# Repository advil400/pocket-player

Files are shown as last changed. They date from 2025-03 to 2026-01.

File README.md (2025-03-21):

# pocket-player

open hardware portable music player and personal computer\
customizable public good for everyday listening and other habits\
\
towards new ways of living & new ecologies of minds and matter

eng. Waking+Life\
prod. 99.9%Pure\
[CERN-OHL-S-2.0](https://choosealicense.com/licenses/cern-ohl-s-2.0/)

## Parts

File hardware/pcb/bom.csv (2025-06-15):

Designator | Quantity | Value | Footprint | Package | MPN | DNP | Mount_Type | Description | Manufacturer_Name | Height | Mouser Part Number | Mouser Price/Stock
C1, C43, C44, C46, C47, C52, C8 | 7 | 10uF | C_0805_2012Metric |  | GRM21BZ71E106KE15K |  | smt | Unpolarized capacitor, small symbol | Murata
C10, C13, C16, C19, C2, C21, C23, C3, C33, C34, C35, C36, C37, C38, C39, C4, C40, C41, C5, C6, C7, C9 | 22 | 100nF | C_0402_1005Metric |  | GRM155R71H104KE14D |  | smt | Unpolarized capacitor, small symbol | Murata
C11, C12 | 2 | 10pF | C_0402_1005Metric |  | GRM1555C1E100GA01D |  | smt | Unpolarized capacitor, small symbol | Murata
C14, C15, C17, C18, C25, C26, C27, C28, C29, C30, C31, C32, C49, C50 | 14 | 2u2 | C_0805_2012Metric |  | GRM21BR71E225KE11L |  | smt | Unpolarized capacitor, small symbol | Murata
C20, C48, C51 | 3 | 4u7 | C_0805_2012Metric |  | GRM21BZ71H475KE15L |  | smt | Unpolarized capacitor, small symbol | Murata
C22, C24 | 2 | 15uF | C_1206_3216Metric |  | GRT31CR60J156KE01L |  | smt | Unpolarized capacitor, small symbol | Murata
C42 | 1 | 1uF | C_0805_2012Metric |  | GCM21BR71H105KA03L |  | smt | Unpolarized capacitor, small symbol | Murata
C45 | 1 | 47nF | C_0603_1608Metric |  | GCM188R71H473KA55D |  | smt | Unpolarized capacitor, small symbol | Murata
D1 | 1 | STAT_LED | LED_Wurth_150044M155260 |  | 150044M155260 |  | smt | RGB LED, red/green/blue/anode | Wurth Elektronik
D2, D3, D4, D5, D6, D7 | 6 | PESD3V3L1BA | D_SOD-323F |  | PESD3V3L1BA,115 |  | smt | Bidirectional transient-voltage-suppression diode, small symbol | Nexperia
D8 | 1 | ~ | LED_0402_1005Metric |  | 150040VS73240 |  | smt | Light emitting diode | Wurth Elektronik
FB1, FB2 | 2 | 120R | R_0805_2012Metric |  | BLM21AG121BH1D |  | smt | Ferrite bead, small symbol | Murata
J2 | 1 | microSD PushPush Receptacle | microSD_HC_Hirose_DM3AT-SF-PEJM5 |  | DM3AT-SF-PEJM5 |  | smt | Micro SD Card Socket with one card detection pin | Hirose
J3 | 1 | AudioJack3_SwitchT | SAMESKY_SJ3-35083B-TR |  | SJ3-35083B-TR |  | tht | Audio Jack, 3 Poles (Stereo / TRS), Switched T Pole (Normalling)
J4 | 1 | USB_C_Input | USB_C_Receptacle_GCT_USB4105-xx-A_16P_TopMnt_Horizontal |  | USB4105-GF-A |  | smt | USB 2.0-only 14P Type-C Receptacle connector | GCT
J5 | 1 | Molex 3p 1.25mm | Molex_PicoBlade_53048-0310_1x03_P1.25mm_Horizontal |  | 53048-0310 |  | tht | Molex PicoBlade 3-pin 1.25mm pitch | Molex
L1 | 1 | 2u2 | L_Coilcraft_XAL4020-XXX |  | XAL4020-222MEC |  | smt | Inductor, small symbol | Coilcraft
L2 | 1 | 2u2 | L_Murata_DFE201610P |  | DFE201612E-2R2M=P2 |  | smt | Inductor, small symbol | Murata
R1, R15, R17, R18, R19, R2, R20, R3, R48, R5, R6, R7, R8, R9 | 14 | 33R | R_0603_1608Metric |  | RT0603DRD0747RL |  | smt | Resistor, small symbol | Yageo
R10, R11, R12, R13, R14, R16, R24, R25, R26, R30, R31, R34, R38, R39, R4, R40, R41, R42, R46 | 19 | 10k | R_0603_1608Metric |  | AT0603FRD0710KL |  | smt | Resistor, small symbol | Yageo
R21, R22, R23 | 3 | 2k2 | R_0603_1608Metric |  | AT0603FRE072K2L |  | smt | Resistor, small symbol | Yageo
R27, R28, R29, R32, R33, R35 | 6 | 1k | R_0603_1608Metric |  | RT0603FRD071KL |  | smt | Resistor, small symbol | Yageo
R36, R37, R43 | 3 | 5k1 | R_0603_1608Metric |  | RT0603FRD075K1L |  | smt | Resistor, small symbol | Yageo
R44 | 1 | 360R | R_0603_1608Metric |  | RT0603FRE07360RL |  | smt | Resistor, small symbol | Yageo
R45 | 1 | 31k6 | R_0603_1608Metric |  | RT0603BRD0731K6L |  | smt | Resistor, small symbol | Yageo
R47 | 1 | 52.3k | R_0603_1608Metric |  | RT0603BRD0752K3L |  | smt | Resistor, small symbol | Yageo
SW1 | 1 | PREV | Panasonic_EVQPUJ_EVQPUA |  | EVQ-PUA02K |  | smt | Push button switch, generic, two pins | Panasonic
SW2 | 1 | VOL+ | Panasonic_EVQPUJ_EVQPUA |  | EVQ-PUA02K |  | smt | Push button switch, generic, two pins | Panasonic
SW3 | 1 | PWR_BTN | Panasonic_EVQPUJ_EVQPUA |  | EVQ-PUA02K |  | smt | Push button switch, generic, two pins | Panasonic
SW4 | 1 | NEXT | Panasonic_EVQPUJ_EVQPUA |  | EVQ-PUA02K |  | smt | Push button switch, generic, two pins | Panasonic
SW5 | 1 | VOL- | Panasonic_EVQPUJ_EVQPUA |  | EVQ-PUA02K |  | smt | Push button switch, generic, two pins | Panasonic
SW6 | 1 | PLAY | Panasonic_EVQPUJ_EVQPUA |  | EVQ-PUA02K |  | smt | Push button switch, generic, two pins | Panasonic
U1 | 1 | STM32F405RGTx | LQFP-64_10x10mm_P0.5mm |  | STM32F405RGT6 |  | smt | STMicroelectronics Arm Cortex-M4 MCU, 1024KB flash, 192KB RAM, 168 MHz, 1.8-3.6V, 51 GPIO, LQFP64 | STMicroelectronics
U2 | 1 | CS43131CNZ | CS43131-CNZR_QFN40 |  | CS43131-CNZR |  | smt |  | Cirrus Logic
U3 | 1 | BQ241920-RGER | Texas_RGE0024H_VQFN-24-1EP_4x4mm_P0.5mm_EP2.7x2.7mm |  | BQ24190RGER |  | smt |  | Texas Instruments
U4 | 1 | USBLC6-2P6 | SOT-666 |  | USBLC6-2P6 |  | smt | Very low capacitance ESD protection diode, 2 data-line, SOT-666 | STMicroelectronics
U5 | 1 | NCV8164AML180TCG | SON65P300X300X100-9N-D |  | NCV8164AML150TCG |  | smt | LDO 300 MA AD 1.8, ULTRA-LOW NOISE AND HIGH PSRR IN DFNW8 | onsemi | 1 | 863-NCV8164AML150TCG | https://www.mouser.co.uk/ProductDetail/onsemi/NCV8164AML150TCG?qs=sPbYRqrBIVl5v6mdwrs2Uw%3D%3D
U6 | 1 | TPS62842DGRR | HVSSOP8_DGR_TEX |  | TPS62842DGRR |  | smt |  | Texas Instruments
Y1 | 1 | 24MHz | Crystal_SMD_SeikoEpson_TSX3225-4Pin_3.2x2.5mm |  | TSX-3225 24.0000MF15X-AC6 |  | smt | Four pin crystal, GND on pins 2 and 4, small symbol | Epson

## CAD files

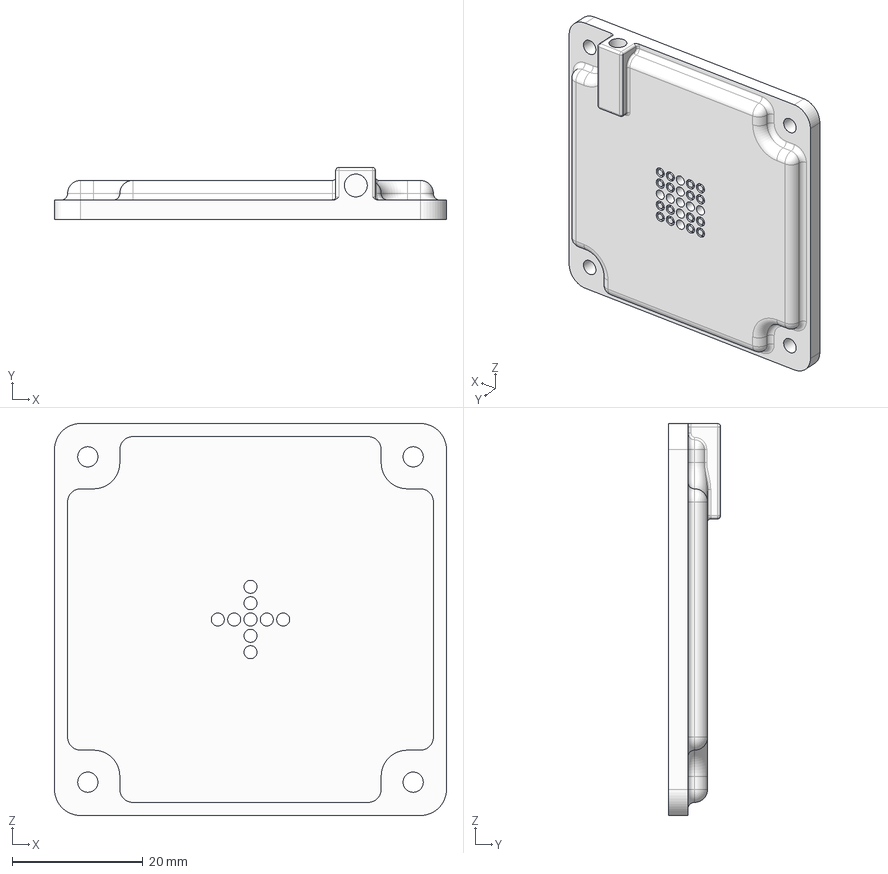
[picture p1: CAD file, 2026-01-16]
hardware/enclosure/shell v10.step
60.0 x 8.00 x 60.0 mm

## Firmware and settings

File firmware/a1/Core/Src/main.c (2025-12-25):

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
/* Includes ------------------------------------------------------------------*/
#include "main.h"
#include "fatfs.h"

/* USER CODE BEGIN Includes */
#include "codec.h"
#include "audio_stream.h"
#include "i2s_player.h"
#include <stdio.h>
/* USER CODE END Includes */

/* USER CODE BEGIN PD */
#define I2S_FRAMES_HALF 1024U
#define I2S_DMA_WORDS (I2S_FRAMES_HALF * 2U * 2U) //channels, halves

#define CODEC_VOL (0x50u) // -40dB

/* USER CODE END PD */

I2C_HandleTypeDef hi2c2;

I2S_HandleTypeDef hi2s2;
DMA_HandleTypeDef hdma_spi2_tx;

SD_HandleTypeDef hsd;
DMA_HandleTypeDef hdma_sdio_rx;
DMA_HandleTypeDef hdma_sdio_tx;

PCD_HandleTypeDef hpcd_USB_OTG_FS;

/* USER CODE BEGIN PV */
static codec_t g_codec;

static audio_stream_t g_stream;
static i2s_player_t g_player;

static uint8_t g_rb[64 * 1024] __attribute__((aligned(4)));
static uint16_t g_i2s_dma[I2S_DMA_WORDS] __attribute__((aligned(4)));
/* USER CODE END PV */

void SystemClock_Config(void);
static void MX_GPIO_Init(void);
static void MX_DMA_Init(void);
static void MX_SDIO_SD_Init(void);
static void MX_I2C2_Init(void);
static void MX_I2S2_Init(void);
static void MX_USB_OTG_FS_PCD_Init(void);
/* USER CODE BEGIN PFP */
static void codec_start(void);
/* USER CODE END PFP */

/**
  * @brief  The application entry point.
  * @retval int
  */
int main(void)
{

  /* MCU Configuration--------------------------------------------------------*/

  /* Reset of all peripherals, Initializes the Flash interface and the Systick. */
  HAL_Init();

  /* Configure the system clock */
  SystemClock_Config();

  /* Initialize all configured peripherals */
  MX_GPIO_Init();
  MX_DMA_Init();
  MX_SDIO_SD_Init();
  MX_I2C2_Init();
  MX_I2S2_Init();
  MX_FATFS_Init();
  MX_USB_OTG_FS_PCD_Init();
  /* USER CODE BEGIN 2 */

codec_start();
stream_init(&g_stream, g_rb, sizeof(g_rb));
i2s_player_init(&g_player, &hi2s2, &g_stream, g_i2s_dma, I2S_DMA_WORDS);

static const TCHAR drive[] = { '0', ':', 0};
static const TCHAR path[] = { '0', ':', '/', 't', 'e', 's', 't', '.', 'w', 'a', 'v', 0};

if (stream_mount(drive) != AUDIO_OK){

	Error_Handler();
}

if (parse_wav(&g_stream, path) != AUDIO_OK){

	Error_Handler();
}

// format constraints
if (g_stream.wav.audio_format != 1  ||
	g_stream.wav.num_chan 	  != 2  ||
	g_stream.wav.bit_depth 	  != 16 ||
	g_stream.wav.sample_rate  != 44100) {
	Error_Handler();
}

//Prime read-ahead so the first DMA fill doesn't underflow
(void)stream_push(&g_stream);

if (i2s_player_start(&g_player) != HAL_OK){
	Error_Handler();
}

// Stabilize clocks //
HAL_Delay(1);

codec_status_t st = codec_music_prep(&g_codec, CODEC_WORD_LEN_16, CODEC_VOL);
if (st != CODEC_OK){
	Error_Handler();
}

st = codec_music_play(&g_codec);
if (st != CODEC_OK) {
	Error_Handler();
}

  /* USER CODE END 2 */

  /* Infinite loop */
  /* USER CODE BEGIN WHILE */
  while (1)
  {
	  (void)stream_push(&g_stream);

	  if (g_stream.rem == 0 && stream_avail(&g_stream) == 0){

		  // Mute + settle + shutdown codec while MCLK up //
		  (void)codec_shutdown(&g_codec);
		  if (codec_shutdown(&g_codec) != CODEC_OK) {
		      Error_Handler();
		  }

		  // Safe to stop I2S / MCLK //
		  (void)i2s_player_stop(&g_player);
		  if (i2s_player_stop(&g_player) != HAL_OK) {
		      Error_Handler();
		  }

		  // Close file + unmount //
		  stream_close(&g_stream);
		  (void)stream_unmount(drive);
		  while (1) {/*done*/}
	  }
    /* USER CODE END WHILE */

    /* USER CODE BEGIN 3 */
  }
  /* USER CODE END 3 */
}

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
/* USER CODE BEGIN 4 */
static void codec_start(void)
{
	codec_status_t st;

	st = codec_init(&g_codec,
					&hi2c2,
					CS_RESET_GPIO_Port,
					CS_RESET_Pin);

	if (st == CODEC_OK) {
		return;
	}

	Error_Handler();
}

void HAL_I2S_TxHalfCpltCallback(I2S_HandleTypeDef *hi2s)
{
	if (hi2s == &hi2s2){
		i2s_player_half(&g_player);
	}
}

void HAL_I2S_TxCpltCallback(I2S_HandleTypeDef *hi2s)
{
	if (hi2s == &hi2s2) {
		i2s_player_full(&g_player);
	}
}

void HAL_I2S_ErrorCallback(I2S_HandleTypeDef *hi2s)
{
	if (hi2s == &hi2s2) {
		i2s_player_error(&g_player);
	}
}
/* USER CODE END 4 */
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


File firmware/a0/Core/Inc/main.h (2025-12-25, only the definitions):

#define PLAY_Pin GPIO_PIN_4
#define PLAY_GPIO_Port GPIOC
#define CS_RESET_Pin GPIO_PIN_8
#define CS_RESET_GPIO_Port GPIOA

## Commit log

2025-06-15 a1
    first prototype
    [PCBWay_bom.csv, PCBWay_positions.csv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]
2025-10-05 update interactive bom to prototype rev.
2025-12-25 firmware version a1
    initial mvp user-written firmware (does not include auto-generated stm32 hal files)
2025-12-25 a0 firmware
    codec i2c config, simple sd + usb mass storage configuration
2025-12-25 a0 firmware
    codec i2c config, simple sd + usb mass storage
2026-01-16 a1
    restructure with near-latest revision
    [PCBWay_bom.csv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]
2026-01-16 Update and rename PCBWay_bom.csv to bom.csv
    [bom.csv]

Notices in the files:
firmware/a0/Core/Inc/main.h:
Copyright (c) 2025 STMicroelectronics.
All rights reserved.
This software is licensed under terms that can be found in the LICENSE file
